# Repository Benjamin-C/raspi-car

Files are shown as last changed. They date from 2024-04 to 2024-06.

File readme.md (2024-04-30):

Raspberry Pi Controlled Little Car
===

This project is to create a small car that can drive around semi-autonomously. It has several cameras that can be used for computer vision or automated measurements, all controlled by a Raspberry Pi.

# Components
1. [Hiwonder Mecanum Wheel Chassis Car Kit](https://www.hiwonder.com/products/mecanum-wheel-chassis-car)
2. [Raspberry Pi 5 8GB](https://www.raspberrypi.com/products/raspberry-pi-5/)
3. [OAK-D Lite Sterioscopic Camera](https://shop.luxonis.com/collections/oak-cameras-1/products/oak-d-lite-1)
4. [Infaray P2 Pro thermal camera](https://www.infiray.com/p2-pro-thermal-camera-for-smartphone/)
5. [Sodium Ion 18650 Batteries](https://srikobatteries.com/product/sodium-ion-18650-3-0v-1-3ah-3-90wh-10c-rechargeable-battery/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)
6. 3d printed camera bracket
7. Car control PCB

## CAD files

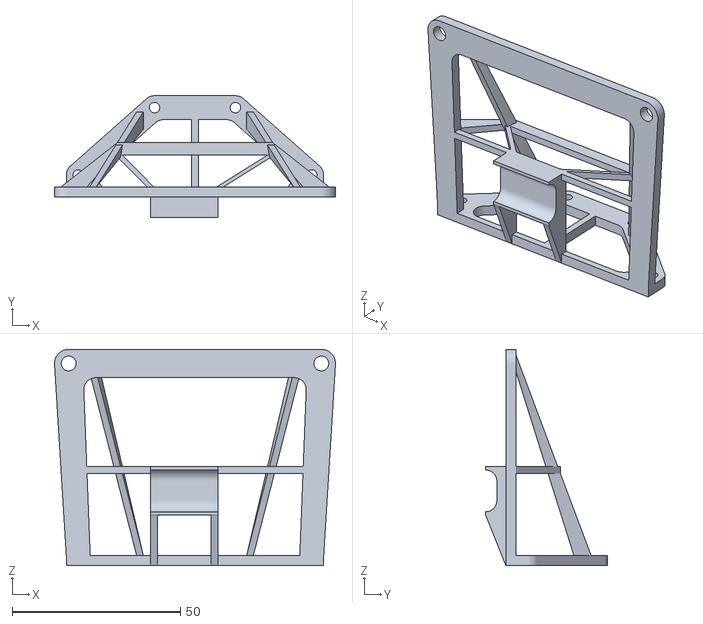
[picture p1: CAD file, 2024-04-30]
3d-model/camerabracket.stl
83.4 x 36.1 x 64.2

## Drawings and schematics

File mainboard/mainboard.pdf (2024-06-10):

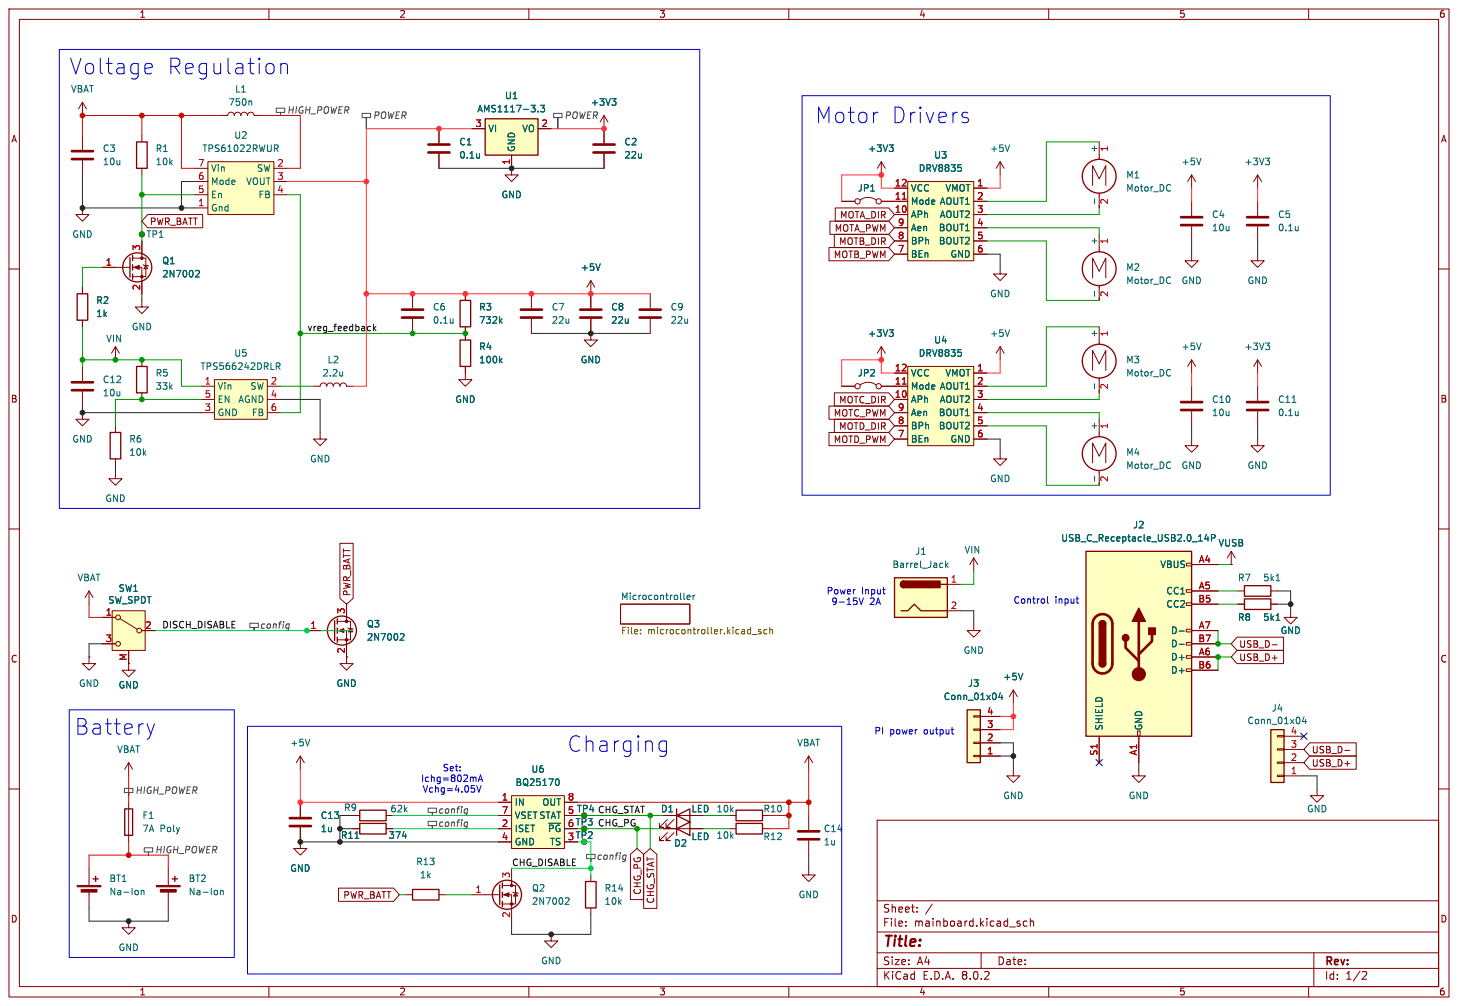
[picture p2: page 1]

1 VO 2 VI 3 U1 AMS1117-3.3 Gnd 1 SW 2 VOUT 3 FB 4 En 5 Mode 6 Vin 7 U2 TPS61022RWUR

-2 M1 VMOT Motor_DC 1 APh 10 Mode 11 VCC 12 AOUT1 2 AOUT2 3 BOUT1 4 BOUT2 5 GND 6 BEn 7 BPh 8 Aen 9 U3 DRV8835 +5V

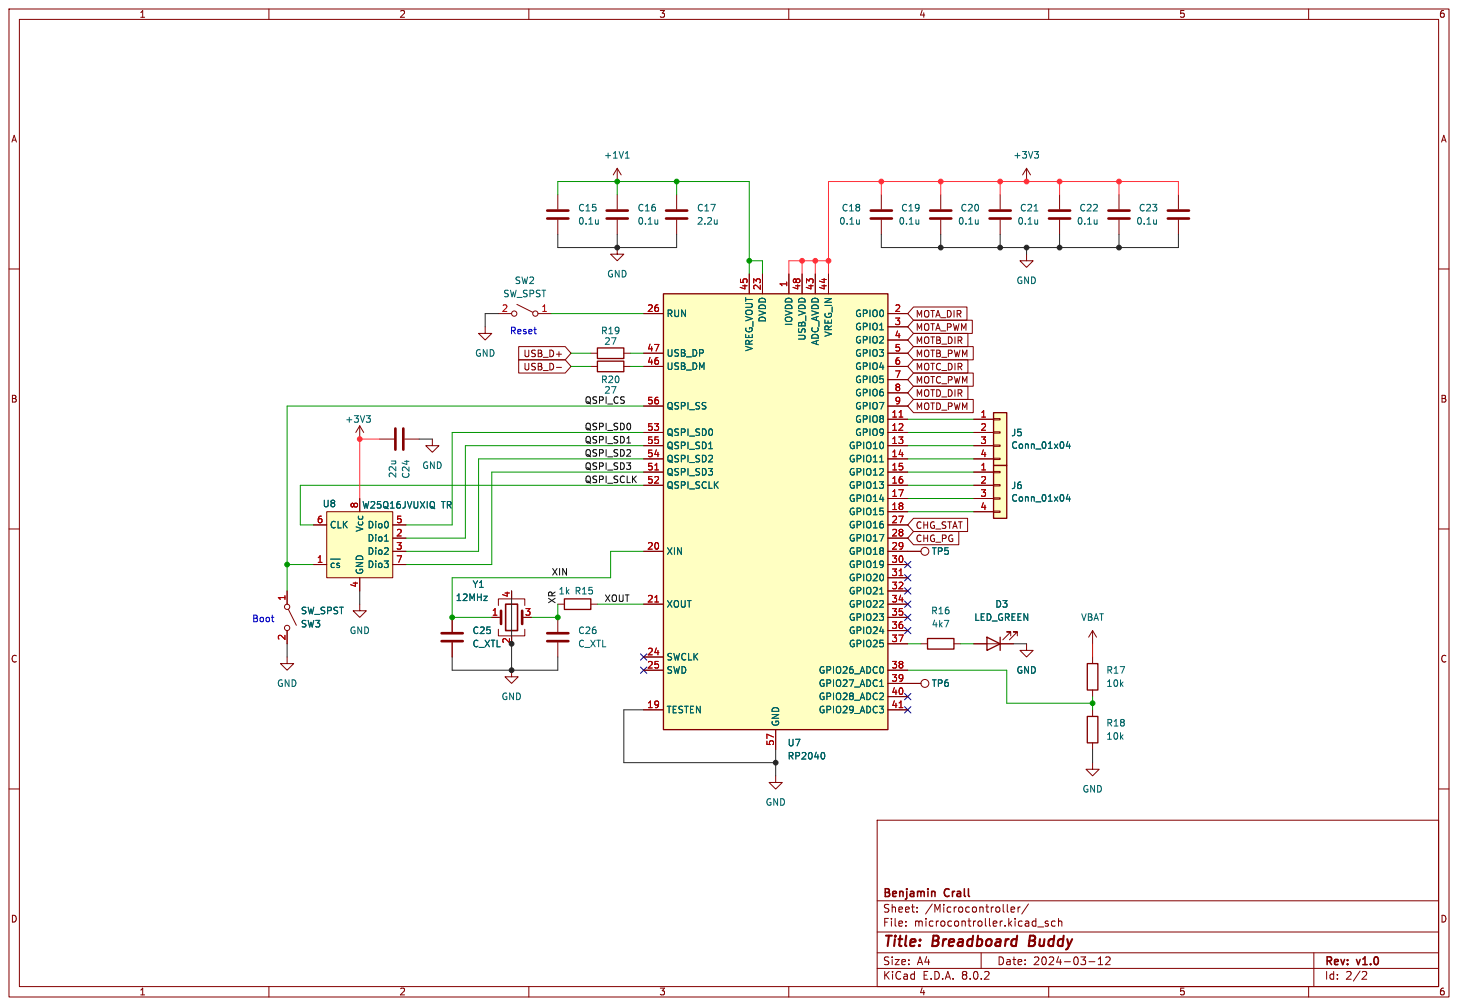
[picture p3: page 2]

1 GPIO8 11 GPIO9 12 GPIO10 13 GPIO11 14 GPIO12 15 GPIO13 16 GPIO14 17 GPIO15 18 TESTEN 19 GPIO0 2 XIN 20 XOUT 21 DVDD 23 SWCLK 24 SWD 25 RUN 26 GPIO16 27 GPIO17 28 GPIO18 29 GPIO1 3 GPIO19 30 GPIO20 31 GPIO21 32 GPIO22 34 GPIO23 35 GPIO24 36 GPIO25 37 GPIO26_ADC0 38 GPIO27_ADC1 39 GPIO2 4 GPIO28_ADC2 40 GPIO29_ADC3 41 ADC_AVDD 43 VREG_IN 44 VREG_VOUT 45 USB_DM 46 USB_DP 47 USB_VDD 48 GPIO3 5 QSPI_SD3 51 QSPI_SCLK 52 QSPI_SD0 53 QSPI_SD2 54 QSPI_SD1 55 QSPI_SS 56 GND 57 GPIO4 6 GPIO5 7 GPIO6 8 GPIO7 9 Y1

1 GPIO8 11 GPIO9 12 GPIO10 13 GPIO11 14 GPIO12 15 GPIO13 16 GPIO14 17 GPIO15 18 TESTEN 19 GPIO0 2 XIN 20 XOUT 21 DVDD 23 SWCLK 24 SWD 25 RUN 26 GPIO16 27 GPIO17 28 GPIO18 29 GPIO1 3 GPIO19 30 GPIO20 31 GPIO21 32 GPIO22 34 GPIO23 35 GPIO24 36 GPIO25 37 GPIO26_ADC0 38 GPIO27_ADC1 39 GPIO2 4 GPIO28_ADC2 40 GPIO29_ADC3 41 ADC_AVDD 43 VREG_IN 44 VREG_VOUT 45 USB_DM 46 USB_DP 47 USB_VDD 48 GPIO3 5 QSPI_SD3 51 QSPI_SCLK 52 QSPI_SD0 53 QSPI_SD2 54 QSPI_SD1 55 QSPI_SS 56 GND 57 GPIO4 6 GPIO5 7 GPIO6 8 GPIO7 9 U7 RP2040 D3

File: microcontroller.kicad_sch Sheet: /Microcontroller/ Benjamin Crall

Id: 2/2 Title: Breadboard Buddy

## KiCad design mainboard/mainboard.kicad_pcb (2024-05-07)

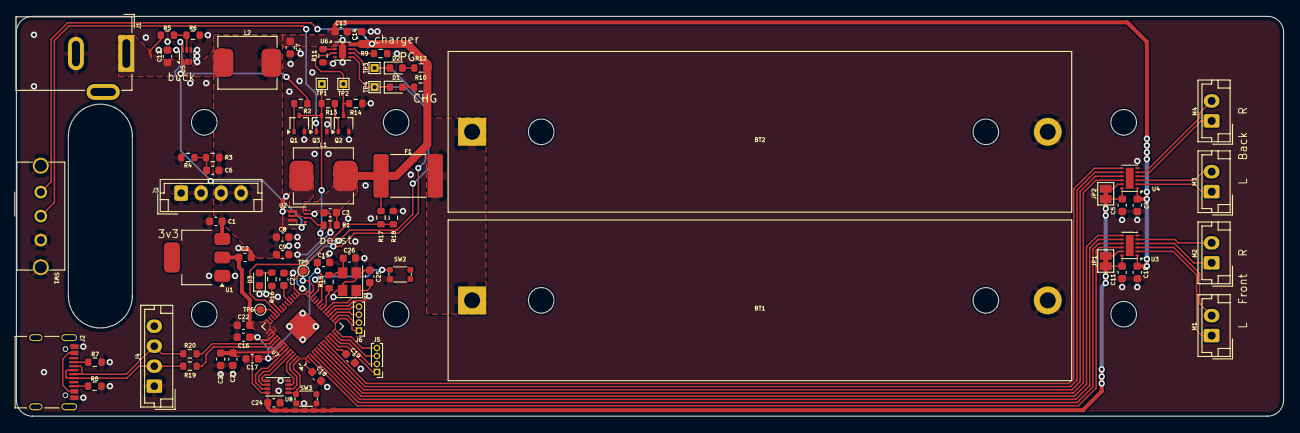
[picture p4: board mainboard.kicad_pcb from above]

Board: 2 copper layers, 158.5 x 50.0 mm, 87 parts (0 on the bottom side), 70 nets.

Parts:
BT1, BT2: Na-Ion; BatteryHolder_MPD_BH-18650-PC2
C1, C5, C6, C11, C15, C16, C18, C19, C20, C21, C22, C23: 0.1u; C_0603_1608Metric
C2, C7, C8, C9, C24: 22u; C_0603_1608Metric
C3, C4, C10, C12: 10u; C_0603_1608Metric
C13, C14: 1u; C_0603_1608Metric
C17: 2.2u; C_0603_1608Metric
C25, C26: C_XTL; C_0603_1608Metric
D1, D2: LED; LED_0603_1608Metric
D3: LED_GREEN; LED_0603_1608Metric
F1: 7A Poly; Fuse_2920_7451Metric
J1: Barrel_Jack; BarrelJack_GCT_DCJ200-10-A_Horizontal
J2: USB_C_Receptacle_USB2.0_14P; USB_C_Receptacle_USB2
J3, J4: Conn_01x04; JST_EH_B4B-EH-A_1x04_P2.50mm_Vertical
J5, J6: Conn_01x04; PinHeader_1x04_P1.00mm_Vertical
JP1, JP2: Jumper_2_Bridged; SolderJumper-2_P1.3mm_Bridged_Pad1.0x1.5mm
L1: 750n; inductor_PA431
L2: 2.2u; inductor_BMRx
M1, M2, M3, M4: Motor_DC; JST_EH_B2B-EH-A_1x02_P2.50mm_Vertical
Q1, Q2, Q3: 2N7002; SOT-323_SC-70
R1, R6, R10, R12, R14, R17, R18: 10k; R_0603_1608Metric
R2, R13, R15: 1k; R_0603_1608Metric
R3: 732k; R_0603_1608Metric
R4: 100k; R_0603_1608Metric
R5: 33k; R_0603_1608Metric
R7, R8: 5k1; R_0603_1608Metric
R9: 62k; R_0603_1608Metric
R11: 374; R_0603_1608Metric
R16: 4k7; R_0603_1608Metric
R19, R20: 27; R_0603_1608Metric
SW1: SW_SPDT
SW2, SW3: SW_SPST; SW_SPST_2.8x1.9
TP1, TP2, TP3, TP4: TestPoint_Small; TestPoint_THTPad_1.0x1.0mm_Drill0.5mm
TP5, TP6: TestPoint; TestPoint_Pad_D1.0mm
U1: AMS1117-3.3; SOT-223-3_TabPin2
U2: TPS61022RWUR; VQFN-7
U3, U4: DRV8835; WSON-12-1EP_3x2mm_P0.5mm_EP1x2.65
U5: TPS566242DRLR; SOT-563
U6: BQ25170; WSON-8-1EP_2x2mm_P0.5mm_EP0.9x1.6mm
U7: RP2040; QFN-56-1EP_7x7mm_P0.4mm_EP3.2x3.2mm
U8: W25Q16JVUXIQ TR; 8-UFDFN
Y1: 12MHz; Crystal_SMD_3225-4Pin_3.2x2.5mm

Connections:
+1V1: C15.1, C16.1, C17.1, U7.23 (DVDD), U7.45 (VREG_VOUT), U7.50 (DVDD)
+3V3: C2.1, C5.1, C11.1, C18.1, C19.1, C20.1, C21.1, C22.1, C23.1, C24.2, JP1.1 (A), JP2.1 (A), U1.2 (VO), U3.12 (VCC), U4.12 (VCC), U7.1 (IOVDD), U7.10 (IOVDD), U7.22 (IOVDD), U7.33 (IOVDD), U7.42 (IOVDD), U7.43 (ADC_AVDD), U7.44 (VREG_IN), U7.48 (USB_VDD), U7.49 (IOVDD), U8.8 (Vcc)
+5V: C1.1, C4.1, C6.1, C7.1, C8.1, C9.1, C10.1, C13.1, J3.3, J3.4, L2.2, R3.1, U1.3 (VI), U2.3 (VOUT), U3.1 (VMOT), U4.1 (VMOT), U6.1 (IN)
/CHG_DISABLE: Q2.3 (D), R14.1, TP2.1, U6.3 (TS)
/DISCH_DISABLE: Q3.1 (G), SW1.2 (B)
/Microcontroller/QSPI_CS: SW3.1 (A), U7.56 (QSPI_SS), U8.1 (~cs)
/Microcontroller/QSPI_SCLK: U7.52 (QSPI_SCLK), U8.6 (CLK)
/Microcontroller/QSPI_SD0: U7.53 (QSPI_SD0), U8.5 (Dio0)
/Microcontroller/QSPI_SD1: U7.55 (QSPI_SD1), U8.2 (Dio1)
/Microcontroller/QSPI_SD2: U7.54 (QSPI_SD2), U8.3 (Dio2)
/Microcontroller/QSPI_SD3: U7.51 (QSPI_SD3), U8.7 (Dio3)
/Microcontroller/XIN: C25.1, U7.20 (XIN), Y1.1
/Microcontroller/XOUT: R15.2, U7.21 (XOUT)
/Microcontroller/XR: C26.1, R15.1, Y1.3
/vreg_feedback: C6.2, R3.2, R4.1, U2.4 (FB), U5.6 (FB)
CHG_PG: D2.1 (K), TP3.1, U6.6 (~PG), U7.28 (GPIO17)
CHG_STAT: D1.1 (K), TP4.1, U6.5 (STAT), U7.27 (GPIO16)
GND: BT1.2 (-), BT2.2 (-), C1.2, C2.2, C3.2, C4.2, C5.2, C7.2, C8.2, C9.2, C10.2, C11.2, C12.2, C13.2, C14.2, C15.2, C16.2, C17.2, C18.2, C19.2, C20.2, C21.2, C22.2, C23.2, C24.1, C25.2, C26.2, D3.1 (K), J1.2, J2.A1 (GND), J2.A12 (GND), J2.B1 (GND), J2.B12 (GND), J3.1, J3.2, J4.1, Q1.2 (S), Q2.2 (S), Q3.2 (S), R4.2, R6.2, R7.2, R8.2, R9.1, R11.2, R14.2, R18.2, SW1.3 (C), SW1.M, SW2.2 (B), SW3.2 (B), U1.1 (GND), U2.1 (Gnd), U2.6 (Mode), U3.6 (GND), U4.6 (GND), U5.3 (GND), U5.4 (AGND), U6.4 (GND), U6.9 (PAD), U7.19 (TESTEN), U7.57 (GND), U8.4 (GND), Y1.2, Y1.4
MOTA_DIR: U3.10 (APh), U7.2 (GPIO0)
MOTA_PWM: U3.9 (Aen), U7.3 (GPIO1)
MOTB_DIR: U3.8 (BPh), U7.4 (GPIO2)
MOTB_PWM: U3.7 (BEn), U7.5 (GPIO3)
MOTC_DIR: U4.10 (APh), U7.6 (GPIO4)
MOTC_PWM: U4.9 (Aen), U7.7 (GPIO5)
MOTD_DIR: U4.8 (BPh), U7.8 (GPIO6)
MOTD_PWM: U4.7 (BEn), U7.9 (GPIO7)
unnamed: BT1.1 (+), BT2.1 (+), F1.2
unnamed: D1.2 (A), R10.1
unnamed: D2.2 (A), R12.1
unnamed: D3.2 (A), R16.1
unnamed: J2.A5 (CC1), R7.1
unnamed: J2.B5 (CC2), R8.1
unnamed: J5.1, U7.11 (GPIO8)
unnamed: J5.2, U7.12 (GPIO9)
unnamed: J5.3, U7.13 (GPIO10)
unnamed: J5.4, U7.14 (GPIO11)
unnamed: J6.1, U7.15 (GPIO12)
unnamed: J6.2, U7.16 (GPIO13)
unnamed: J6.3, U7.17 (GPIO14)
unnamed: J6.4, U7.18 (GPIO15)
unnamed: JP1.2 (B), U3.11 (Mode)
unnamed: JP2.2 (B), U4.11 (Mode)
unnamed: M1.1 (+), U3.2 (AOUT1)
unnamed: M1.2 (-), U3.3 (AOUT2)
unnamed: M2.1 (+), U3.4 (BOUT1)
unnamed: M2.2 (-), U3.5 (BOUT2)
unnamed: M3.1 (+), U4.2 (AOUT1)
unnamed: M3.2 (-), U4.3 (AOUT2)
unnamed: M4.1 (+), U4.4 (BOUT1)
unnamed: M4.2 (-), U4.5 (BOUT2)
unnamed: Q1.1 (G), R2.1
unnamed: Q2.1 (G), R13.2
unnamed: SW2.1 (A), U7.26 (RUN)
unnamed: L1.2, U2.2 (SW)
unnamed: R5.2, R6.1, U5.5 (EN)
unnamed: L2.1, U5.2 (SW)
unnamed: R11.1, U6.2 (ISET)
unnamed: R9.2, U6.7 (VSET)
unnamed: TP5.1, U7.29 (GPIO18)
unnamed: R16.2, U7.37 (GPIO25)
unnamed: R17.2, R18.1, U7.38 (GPIO26_ADC0)
unnamed: TP6.1, U7.39 (GPIO27_ADC1)
unnamed: R20.2, U7.46 (USB_DM)
unnamed: R19.2, U7.47 (USB_DP)
PWR_BATT: Q1.3 (D), Q3.3 (D), R1.2, R13.1, TP1.1, U2.5 (En)
USB_D+: J2.A6 (D+), J2.B6 (D+), J4.2, R19.1
USB_D-: J2.A7 (D-), J2.B7 (D-), J4.3, R20.1
VBAT: C3.1, C14.1, F1.1, L1.1, R1.1, R10.2, R12.2, R17.1, SW1.1 (A), U2.7 (Vin), U6.8 (OUT)
VIN: C12.1, J1.1, R2.2, R5.1, U5.1 (Vin)
VUSB: J2.A4 (VBUS), J2.A9 (VBUS), J2.B4 (VBUS), J2.B9 (VBUS)

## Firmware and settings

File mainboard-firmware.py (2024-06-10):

import time
import board
import digitalio
import pwmio

# led = pwmio.PWMOut(board.LED, frequency=5000, duty_cycle=0)

PWM_PIN = [board.GP1, board.GP3, board.GP5, board.GP7]
DIR_PIN = [board.GP0, board.GP2, board.GP4, board.GP6]

PWM: pwmio.PWMOut = []
DIR: digitalio.DigitalInOut = []

# FL FR BL BR
SCALE = [-1, 1, -1, 1]

# Set up output pins
for pin in PWM_PIN:
    PWM.append(pwmio.PWMOut(pin, frequency=5000, duty_cycle=0))

for pin in DIR_PIN:
    dpin = digitalio.DigitalInOut(pin)
    dpin.direction = digitalio.Direction.OUTPUT
    DIR.append(dpin)

def allOff():
    for mot in PWM:
        mot.duty_cycle = 0

while True:
    try:
        val = input()
        vals = val.split(" ")
        for i in range(min(len(vals), 4)):
            v = float(vals[i]) * SCALE[i]
            print(f"Set val {i} to {int(abs(v) * 65535)}")
            PWM[i].duty_cycle = int(abs(v) * 65535)
            DIR[i].value = v > 0
    except Exception as e:
        print(e)
        allOff()

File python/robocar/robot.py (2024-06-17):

import serial
import time

class Robot():
    def __init__(self, port: str = "/dev/ttyACM0") -> None:
        self._serial = None
        self.__running = False
        self.__port = port

        self.speeds = [0, 0, 0, 0]
        ''' Motor speeds [-1,1] in the order FL FR BL BR '''

    @property
    def port(self):
        return self.__port
    
    @property
    def running(self):
        return self.__running
    
    def __enter__(self):
        self.init()
        return self
    
    def __exit__(self, exceptionType, exceptionValue, exceptionTraceback):
        self.deinit()
    
    def init(self):
        if not self.running:
            try:
                self._serial = serial.Serial(self.port)
                # self._serial.open()
                self.__running = True
                # print("Fake opened! Ya!")
            except:
                print("Could not open serial port")
        else:
            print("Already running")

    def deinit(self):
        if self.running:
            self.stop()
            self._serial.close()
            # print("Fake close! Ya!")

    def _serialPrint(self, msg: str):
        # print("Serial msg:" + msg)
        # print("Start print")
        self._serial.write((msg + "\r\n").encode("utf-8"))
        self._serial.reset_input_buffer()
        # print("Stop print")

    def sendDriveCommand(self, fl: float = None, fr: float = None, bl: float = None, br: float = None):
        ''' Sends the set speeds to the motors '''
        if fl is not None and (isinstance(fl, list) or isinstance(fl, tuple)):
            # The user gave a list of values. Use it directly
            self.speeds = list(fl)
        elif fl is not None and fr is not None and bl is not None and br is not None:
            # 4 separate values given. Turn them into the list
            self.speeds = [fl, fr, bl, br]
        # Send the values
        self._serialPrint(' '.join([str(s) for s in self.speeds]))

    def driveForward(self, speed: float = 1, time: int = None):
        ''' Drive the robot forward at the set speed. Defaults to 1 if not specified '''
        self.sendDriveCommand(speed, speed, speed, speed)
        if time is not None:
            self.stop(time)

    def driveBackward(self, speed: float = 1, time: int = None):
        ''' Drive the robot backward at the set speed. Defaults to 1 if not specified '''
        self.sendDriveCommand(-speed, -speed, -speed, -speed)
        if time is not None:
            self.stop(time)

    def driveLeft(self, speed: float = 1, time: int = None):
        ''' Drive the robot straight left at the set speed. Defaults to 1 if not specified '''
        self.sendDriveCommand(-speed, speed, speed, -speed)
        if time is not None:
            self.stop(time)

    def driveRight(self, speed: float = 1, time: int = None):
        ''' Drive the robot straight right at the set speed. Defaults to 1 if not specified '''
        self.sendDriveCommand(speed, -speed, -speed, speed)
        if time is not None:
            self.stop(time)

    def turnLeft(self, speed: float = 1, time: int = None):
        ''' Turn the robot left at the set speed. Defaults to 1 if not specified '''
        self.sendDriveCommand(-speed, speed, -speed, speed)
        if time is not None:
            self.stop(time)

    def turnRight(self, speed: float = 1, time: int = None):
        ''' Turn the robot right at the set speed. Defaults to 1 if not specified '''
        self.sendDriveCommand(speed, -speed, speed, -speed)
        if time is not None:
            self.stop(time)

    def stop(self, delay: int = None):
        ''' Stops the car. Optionally waits delay seconds first '''
        if delay is not None:
            time.sleep(delay)
        self.sendDriveCommand(0, 0, 0, 0)

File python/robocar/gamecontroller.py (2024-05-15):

# Better looking logging
import logging
logging.basicConfig()
log = logging.getLogger("controller")
log.setLevel(logging.DEBUG)

# Get info from joystick
# TODO pick a differnet lib that is less resource intensive
import pygame
pygame.init()

# Threads to do things
import threading

# SteelSeries Stratus XL controller mapping:
# Buttons:
# 0:  A
# 1:  B
# 3:  X
# 4:  Y
# 11: >
# 6:  L1
# 7:  R1
# Axes:
# 0: L horiz +right
# 1: L vert  +down
# 2: R horiz +right
# 3: R vert  +down
# 4: rtrig   +pressed
# 5: ltrig   +pressed

class GameController():
    # Controller axis numbers
    AXES_LEFT_HORIZ: int = 0
    AXES_LEFT_VERT: int = 1
    AXES_LEFT_TRIGGER: int = 4
    AXES_RIGHT_HORIZ: int = 2
    AXES_RIGHT_VERT: int = 3
    AXES_RIGHT_TRIGGER: int = 5

    # A scale factor to apply to each axis. Used to make all joysticks +,+ be up and right
    AXIS_SCALE = {AXES_LEFT_HORIZ: 1, AXES_LEFT_VERT: -1, AXES_LEFT_TRIGGER: 1, AXES_RIGHT_HORIZ: 1, AXES_RIGHT_VERT: -1, AXES_RIGHT_TRIGGER: 1}

    # Controller button numbers
    BUTTON_A: int = 0
    BUTTON_B: int = 1
    BUTTON_X: int = 3
    BUTTON_Y: int = 4
    BUTTON_L1: int = 6
    BUTTON_R1: int = 7

    def __init__(self, joynum:int=0):
        # Initialize joysticks
        pygame.joystick.init()
        # Check if the joystick exists
        ct = pygame.joystick.get_count()
        log.debug(f"There are {ct} joysticks")
        if ct < joynum+1:
            log.critical("No controller detected, aborting")
            return
        # Get the joystick
        self.controller: pygame.joystick.Joystick = pygame.joystick.Joystick(joynum)
        self.controller.init()
        log.debug(f"My joystick has {self.controller.get_numaxes()} axes, {self.controller.get_numhats()} hats, and {self.controller.get_numbuttons()} buttons")
        log.info(f"Joystick connected")

        self._event = threading.Event()

    def __enter__(self):
        self.start()
        return self

    def __exit__(self, exceptionType, exceptionValue, exceptionTraceback):
        # super().__exit__(exceptionType, exceptionValue, exceptionTraceback)
        self.stop()

    def start(self):
        self._event.set()
        self.pollthread = threading.Thread(target=self.__runthread)
        self.pollthread.start()

    def stop(self):
        self._event.clear()
        pygame.event.post(pygame.event.Event(pygame.USEREVENT))
        self._event.wait()

    def __runthread(self):
        while self._event.isSet():
            # We don't need to process the events now, just make sure they are captured.
            pygame.event.get()
        self._event.set()

    def getAxies(self, axis:int) -> float:
        ''' Gets the position of an axis. '''
        return self.controller.get_axis(axis) * self.AXIS_SCALE[axis]
    
    def getButton(self, button:int) -> bool:
        ''' Gets the state of a button '''
        return self.controller.get_button(button)

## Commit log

2024-04-30 Prepared for PCB layout
    [mainboard.kicad_pcb, mainboard.kicad_sch, microcontroller.kicad_sch]
2024-05-06 Added some 3d libs and started routing
    [mainboard.kicad_pcb, mainboard.kicad_sch, microcontroller.kicad_sch]
2024-05-07 More building
    [mainboard.kicad_pcb, mainboard.kicad_sch, microcontroller.kicad_sch]
2024-05-07 Finished routing
    [mainboard.kicad_pcb, mainboard.kicad_sch, microcontroller.kicad_sch]
2024-05-07 Trace Edits
    [mainboard.kicad_pcb]
2024-05-15 Added camera files
